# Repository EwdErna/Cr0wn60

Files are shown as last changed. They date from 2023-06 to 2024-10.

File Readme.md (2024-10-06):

# Cr0wn60

Cr0wn60 配下の特徴を持つキーボードです。

- TreadStone 配列ベースの左右対称配列
- RP2040 採用の PCB
- Friction O-ring Mount の 3 ピースケース

ファームウェアは以下のリポジトリから取得可能です。  
[Ewderna/qmk_firmware ewderna_22 branch](https://github.com/EwdErna/qmk_firmware/tree/dev/ewderna_22)

## Build Guide

### 同梱物

- PCB
  - デフォルトのファームウェアを書き込み済み
- スイッチプレート
- ケース
  - トップケース
  - ミドルプレート
  - ボトムケース
- O-ring ID185x3.55mm
- Unified Daughter Board S1 / molex Pico EasyMate Cable

> [!Note]  
> ProtoType 版ではスイッチプレート、ケースはデータのみの配布となります。  
> また、O-ring については付属しません。ご自身で購入をお願いします。

### 別途必要なもの

- キースイッチ x60
  - Cherry MX 互換のみ対応
- スタビライザー
  - PCBマウント 2U x3
- LED x15 (Optional)
  - SK6812MINI-E 互換品
- USB Type-C ケーブル
- キーキャップ x60
  - 1U x48
  - 1.25U x5
  - 1.5U x2
  - 1.75U x2
  - 2.25U x3

### 組み立て手順

#### LEDのはんだ付け(Optional)

15個のLEDをはんだ付けします。  

#### スタビライザーの取り付け

PCBにスタビライザーを取り付けます。  
PCB表面にスタビライザーのワイヤー側を示すシルクがあります。  
向きを間違えないよう注意してください。

#### スイッチプレートにキースイッチの取り付け

すべてのキースイッチをスイッチプレートに取り付けます。

#### キースイッチのはんだ付け

プレートごとキースイッチをPCBに取り付け、裏面からはんだ付けします。

#### 動作確認

UDBに付属のケーブルをUDB、PCBそれぞれのハウジングに取り付けます。  
PCとUDBをType-Cケーブルでつなぎ、[Remap](https://remap-keys.app)に接続します。  
CUSTOMIZE YOUR KEYBOARDからCr0wn60を選択したのち、Test Matrixモードを使用し全キーが反応することを確認します。  
オプションのLEDを取り付けている場合もここで確認します。  
> [!TIP]  
> LEDが途中から光らない場合は、光らないLEDかその直前の番号のLEDについてはんだ付けを見直してください。  
> はんだ付けを直しても光らない場合はLEDが壊れている可能性がありますので交換してみてください。

> [!TIP]  
> proto.1、proto.2ではLED番号が逆転しています。LED15が一番最初のLEDで、LED1が一番最後のLEDです。

#### O-ringの取り付け

スイッチプレートとPCBの隙間に、スイッチに引っかかるようにO-ringを取り付けます。  
下側左右の角部分に余裕を持たせるように掛けておくとケースに入れやすくなります。

#### ケースの組み立て

ボトムケース、ミドルプレート、トップケースの順に重ね、ボトムケースの裏側からM3ねじ8本で固定します。  
ミドルプレートの向きに気を付けてください。角の隙間が狭いほうが左側に来るように重ねます。

#### UDBの取り付け

UDBを、付属のねじでボトムケースに固定します。  
付属のケーブルをUDB、PCBのハウジングにそれぞれ取り付けます。向きは特にありません。

#### ケースにPCBの取り付け

PCBをケースに収めます。  
下側左右の角部分に張ったO-ringをトップケースの角に押し付けながら、上側をケース内に押し込みます。  
最後に奥まで押し込んで取付完了です。

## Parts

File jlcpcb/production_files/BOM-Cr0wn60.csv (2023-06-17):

Comment | Designator | Footprint | LCSC
1k | R3,R4,R5 | R_0402_1005Metric | C11702
0.1u | C1,C11,C2,C3,C4,C7,C8 | C_0402_1005Metric | C1525
10u | C10,C9 | C_0402_1005Metric | C15525
27p | C12,C13 | C_0402_1005Metric | C1557
RP2040_QFN_56 | U3 | QFN-56-1EP_7x7mm_P0.4mm_EP3.2x3.2mm | C2040
22 | R1,R2 | R_0402_1005Metric | C25092
SW_Push | SWR0,SWR1 | TS-1088R-02026 | C455280
YS-SK6812MINI-E-Small | LED1,LED10,LED11,LED12,LED13,LED14,LED15,LED2,LED3,LED4,LED5,LED6,LED7,LED8,LED9 | YS-SK6812MINI-E_rev | C5149201
1u | C5,C6 | C_0402_1005Metric | C52923
Conn_01x04_MountingPin | J1 | Pico-EZmate | C588524
AMS1117 | U1 | SOT-223-3_TabPin2 | C6186
D_Small | D1,DK1,DK10,DK12,DK13,DK14,DK15,DK16,DK17,DK2,DK20,DK21,DK23,DK24,DK25,DK26,DK3,DK30,DK31,DK32,DK34,DK35,DK36,DK37,DK4,DK40,DK41,DK42,DK43,DK45,DK46,DK5,DK50,DK51,DK52,DK53,DK54,DK56,DK57,DK6,DK60,DK61,DK62,DK63,DK64,DK65,DK70,DK71,DK72,DK73,DK74,DK75,DK76,DK80,DK81,DK82,DK83,DK84,DK85,DK86,DK87,DR0,DR1,DR2,DR3,DR4,DR5,DR6,DR7,DR8 | D_SOD-123 | C81598
12M | Y1 | Crystal_SMD_3225-4Pin_3.2x2.5mm | C9002
W25Q128JVS | U2 | SOIC-8_5.23x5.23mm_P1.27mm | C97521

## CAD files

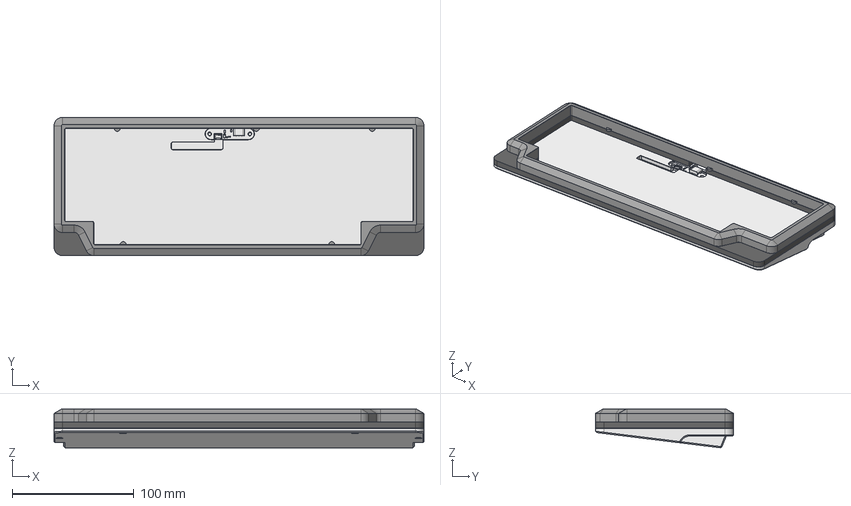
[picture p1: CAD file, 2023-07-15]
Case/proto1/Cr0wn60.FCStd
304.2 x 113.7 x 31.7 mm
uDB-S1-3D-model

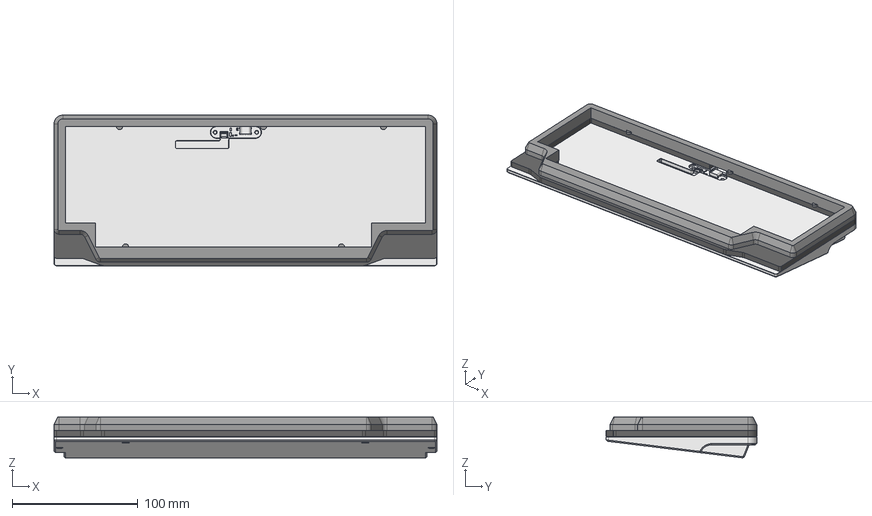
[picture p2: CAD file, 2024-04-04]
Case/proto2/Cr0wn60.FCStd
304.2 x 119.7 x 32.4 mm
uDB-S1-3D-model

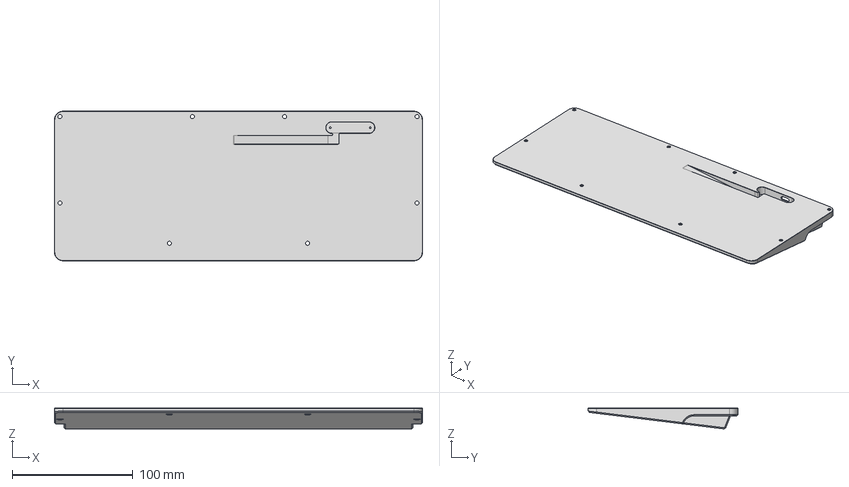
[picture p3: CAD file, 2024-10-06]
Case/proto3/Cr0wn60_2.FCStd
304.2 x 123.7 x 17.3 mm

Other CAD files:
Case/proto3/Cr0wn60_2.blend

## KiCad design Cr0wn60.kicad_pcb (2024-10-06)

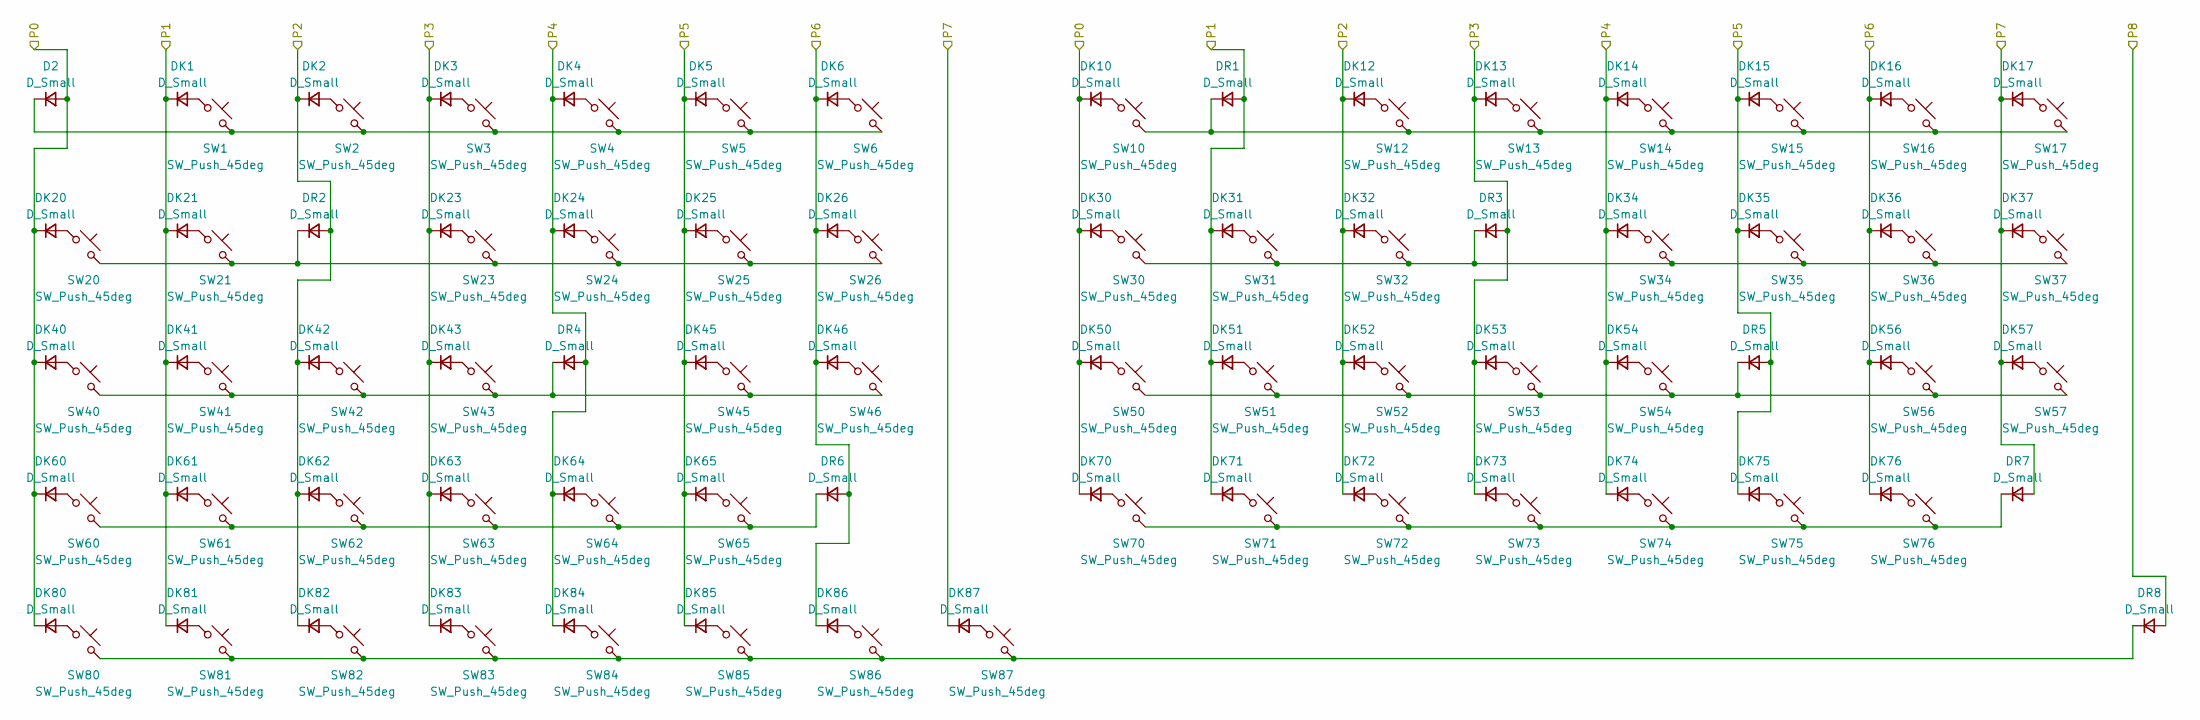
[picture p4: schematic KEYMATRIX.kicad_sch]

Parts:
D2: D_Small
DK1, DK2, DK3, DK4, DK5, DK6, DK10, DK12, DK13, DK14, DK15, DK16, DK17, DK20, DK21, DK23, DK24, DK25, DK26, DK30, DK31, DK32, DK34, DK35, DK36, DK37, DK40, DK41, DK42, DK43, DK45, DK46, DK50, DK51, DK52, DK53, DK54, DK56, DK57, DK60, DK61, DK62, DK63, DK64, DK65, DK70, DK71, DK72, DK73, DK74, DK75, DK76, DK80, DK81, DK82, DK83, DK84, DK85, DK86, DK87: D_Small; D_SOD-123
DR1, DR2, DR3, DR4, DR5, DR6, DR7, DR8: D_Small; D_SOD-123
SW1, SW2, SW3, SW4, SW5, SW6, SW10, SW12, SW13, SW14, SW15, SW16, SW17, SW21, SW23, SW24, SW25, SW26, SW30, SW31, SW32, SW34, SW35, SW36, SW41, SW42, SW43, SW45, SW46, SW50, SW51, SW52, SW53, SW54, SW56, SW61, SW62, SW63, SW64, SW65, SW70, SW71, SW72, SW73, SW74, SW75, SW82, SW85: SW_Push_45deg; SW_Cherry_MX1A_1.00u_PCB
SW20, SW37: SW_Push_45deg; SW_Cherry_MX1A_1.50u_PCB
SW40, SW76: SW_Push_45deg; SW_Cherry_MX1A_1.75u_PCB
SW57, SW83, SW84: SW_Push_45deg; SW_Cherry_MX1A_2.25u_PCB
SW60, SW80, SW81, SW86, SW87: SW_Push_45deg; SW_Cherry_MX1A_1.25u_PCB

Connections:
/P0: D2.2 (A), DK10.1 (K), DK20.1 (K), DK30.1 (K), DK40.1 (K), DK50.1 (K), DK60.1 (K), DK70.1 (K), DK80.1 (K); also elsewhere on the board
/P1: DK1.1 (K), DK21.1 (K), DK31.1 (K), DK41.1 (K), DK51.1 (K), DK61.1 (K), DK71.1 (K), DK81.1 (K), DR1.2 (A); also elsewhere on the board
/P2: DK2.1 (K), DK12.1 (K), DK32.1 (K), DK42.1 (K), DK52.1 (K), DK62.1 (K), DK72.1 (K), DK82.1 (K), DR2.2 (A); also elsewhere on the board
/P3: DK3.1 (K), DK13.1 (K), DK23.1 (K), DK43.1 (K), DK53.1 (K), DK63.1 (K), DK73.1 (K), DK83.1 (K), DR3.2 (A); also elsewhere on the board
/P4: DK4.1 (K), DK14.1 (K), DK24.1 (K), DK34.1 (K), DK54.1 (K), DK64.1 (K), DK74.1 (K), DK84.1 (K), DR4.2 (A); also elsewhere on the board
/P5: DK5.1 (K), DK15.1 (K), DK25.1 (K), DK35.1 (K), DK45.1 (K), DK65.1 (K), DK75.1 (K), DK85.1 (K), DR5.2 (A); also elsewhere on the board
/P6: DK6.1 (K), DK16.1 (K), DK26.1 (K), DK36.1 (K), DK46.1 (K), DK56.1 (K), DK76.1 (K), DK86.1 (K), DR6.2 (A); also elsewhere on the board
/P7: DK17.1 (K), DK37.1 (K), DK57.1 (K), DK87.1 (K), DR7.2 (A); also elsewhere on the board
/P8: DR8.2 (A); also elsewhere on the board
unnamed: DK1.2 (A), SW1.1
unnamed: DK2.2 (A), SW2.1
unnamed: DK3.2 (A), SW3.1
unnamed: DK4.2 (A), SW4.1
unnamed: DK5.2 (A), SW5.1
unnamed: DK6.2 (A), SW6.1
unnamed: DK10.2 (A), SW10.1
unnamed: DK12.2 (A), SW12.1
unnamed: DK13.2 (A), SW13.1
unnamed: DK14.2 (A), SW14.1
unnamed: DK15.2 (A), SW15.1
unnamed: DK16.2 (A), SW16.1
unnamed: DK17.2 (A), SW17.1
unnamed: DK20.2 (A), SW20.1
unnamed: DK21.2 (A), SW21.1
unnamed: DK23.2 (A), SW23.1
unnamed: DK24.2 (A), SW24.1
unnamed: DK25.2 (A), SW25.1
unnamed: DK26.2 (A), SW26.1
unnamed: DK30.2 (A), SW30.1
unnamed: DK31.2 (A), SW31.1
unnamed: DK32.2 (A), SW32.1
unnamed: DK34.2 (A), SW34.1
unnamed: DK35.2 (A), SW35.1
unnamed: DK36.2 (A), SW36.1
unnamed: DK37.2 (A), SW37.1
unnamed: DK40.2 (A), SW40.1
unnamed: DK41.2 (A), SW41.1
unnamed: DK42.2 (A), SW42.1
unnamed: DK43.2 (A), SW43.1
unnamed: DK45.2 (A), SW45.1
unnamed: DK46.2 (A), SW46.1
unnamed: DK50.2 (A), SW50.1
unnamed: DK51.2 (A), SW51.1
unnamed: DK52.2 (A), SW52.1
unnamed: DK53.2 (A), SW53.1
unnamed: DK54.2 (A), SW54.1
unnamed: DK56.2 (A), SW56.1
unnamed: DK57.2 (A), SW57.1
unnamed: DK60.2 (A), SW60.1
unnamed: DK61.2 (A), SW61.1
unnamed: DK62.2 (A), SW62.1
unnamed: DK63.2 (A), SW63.1
unnamed: DK64.2 (A), SW64.1
unnamed: DK65.2 (A), SW65.1
unnamed: DK70.2 (A), SW70.1
unnamed: DK71.2 (A), SW71.1
unnamed: DK72.2 (A), SW72.1
unnamed: DK73.2 (A), SW73.1
unnamed: DK74.2 (A), SW74.1
unnamed: DK75.2 (A), SW75.1
unnamed: DK76.2 (A), SW76.1
unnamed: DK80.2 (A), SW80.1
unnamed: DK81.2 (A), SW81.1
unnamed: DK82.2 (A), SW82.1
unnamed: DK83.2 (A), SW83.1
unnamed: DK84.2 (A), SW84.1
unnamed: DK85.2 (A), SW85.1
unnamed: DK86.2 (A), SW86.1
unnamed: DK87.2 (A), SW87.1
unnamed 92: D2.1 (K), SW1.2, SW2.2, SW3.2, SW4.2, SW5.2, SW6.2; also elsewhere on the board
unnamed: DR1.1 (K), SW10.2, SW12.2, SW13.2, SW14.2, SW15.2, SW16.2, SW17.2
unnamed: DR2.1 (K), SW20.2, SW21.2, SW23.2, SW24.2, SW25.2, SW26.2
unnamed: DR3.1 (K), SW30.2, SW31.2, SW32.2, SW34.2, SW35.2, SW36.2, SW37.2
unnamed: DR4.1 (K), SW40.2, SW41.2, SW42.2, SW43.2, SW45.2, SW46.2
unnamed: DR5.1 (K), SW50.2, SW51.2, SW52.2, SW53.2, SW54.2, SW56.2, SW57.2
unnamed: DR6.1 (K), SW60.2, SW61.2, SW62.2, SW63.2, SW64.2, SW65.2
unnamed: DR7.1 (K), SW70.2, SW71.2, SW72.2, SW73.2, SW74.2, SW75.2, SW76.2
unnamed: DR8.1 (K), SW80.2, SW81.2, SW82.2, SW83.2, SW84.2, SW85.2, SW86.2, SW87.2

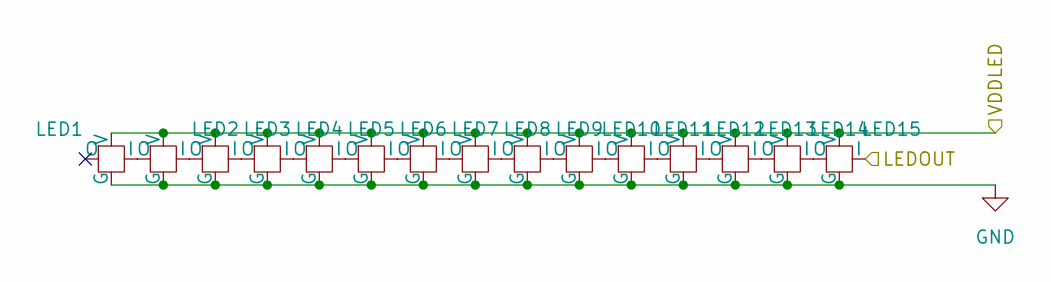
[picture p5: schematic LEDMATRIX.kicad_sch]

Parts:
LED1, LED2, LED3, LED4, LED5, LED6, LED7, LED8, LED9, LED10, LED11, LED12, LED13, LED14, LED15: YS-SK6812MINI-E-Small; YS-SK6812MINI-E_rev

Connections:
/LED: LED15.4 (I); also elsewhere on the board
/VDDLED: LED1.1 (V), LED2.1 (V), LED3.1 (V), LED4.1 (V), LED5.1 (V), LED6.1 (V), LED7.1 (V), LED8.1 (V), LED9.1 (V), LED10.1 (V), LED11.1 (V), LED12.1 (V), LED13.1 (V), LED14.1 (V), LED15.1 (V); also elsewhere on the board
GND: LED1.3 (G), LED2.3 (G), LED3.3 (G), LED4.3 (G), LED5.3 (G), LED6.3 (G), LED7.3 (G), LED8.3 (G), LED9.3 (G), LED10.3 (G), LED11.3 (G), LED12.3 (G), LED13.3 (G), LED14.3 (G), LED15.3 (G); also elsewhere on the board
unnamed: LED1.4 (I), LED2.2 (O)
unnamed: LED2.4 (I), LED3.2 (O)
unnamed: LED3.4 (I), LED4.2 (O)
unnamed: LED4.4 (I), LED5.2 (O)
unnamed: LED5.4 (I), LED6.2 (O)
unnamed: LED6.4 (I), LED7.2 (O)
unnamed: LED7.4 (I), LED8.2 (O)
unnamed: LED8.4 (I), LED9.2 (O)
unnamed: LED10.4 (I), LED11.2 (O)
unnamed: LED9.4 (I), LED10.2 (O)
unnamed: LED11.4 (I), LED12.2 (O)
unnamed: LED12.4 (I), LED13.2 (O)
unnamed: LED13.4 (I), LED14.2 (O)
unnamed: LED14.4 (I), LED15.2 (O)

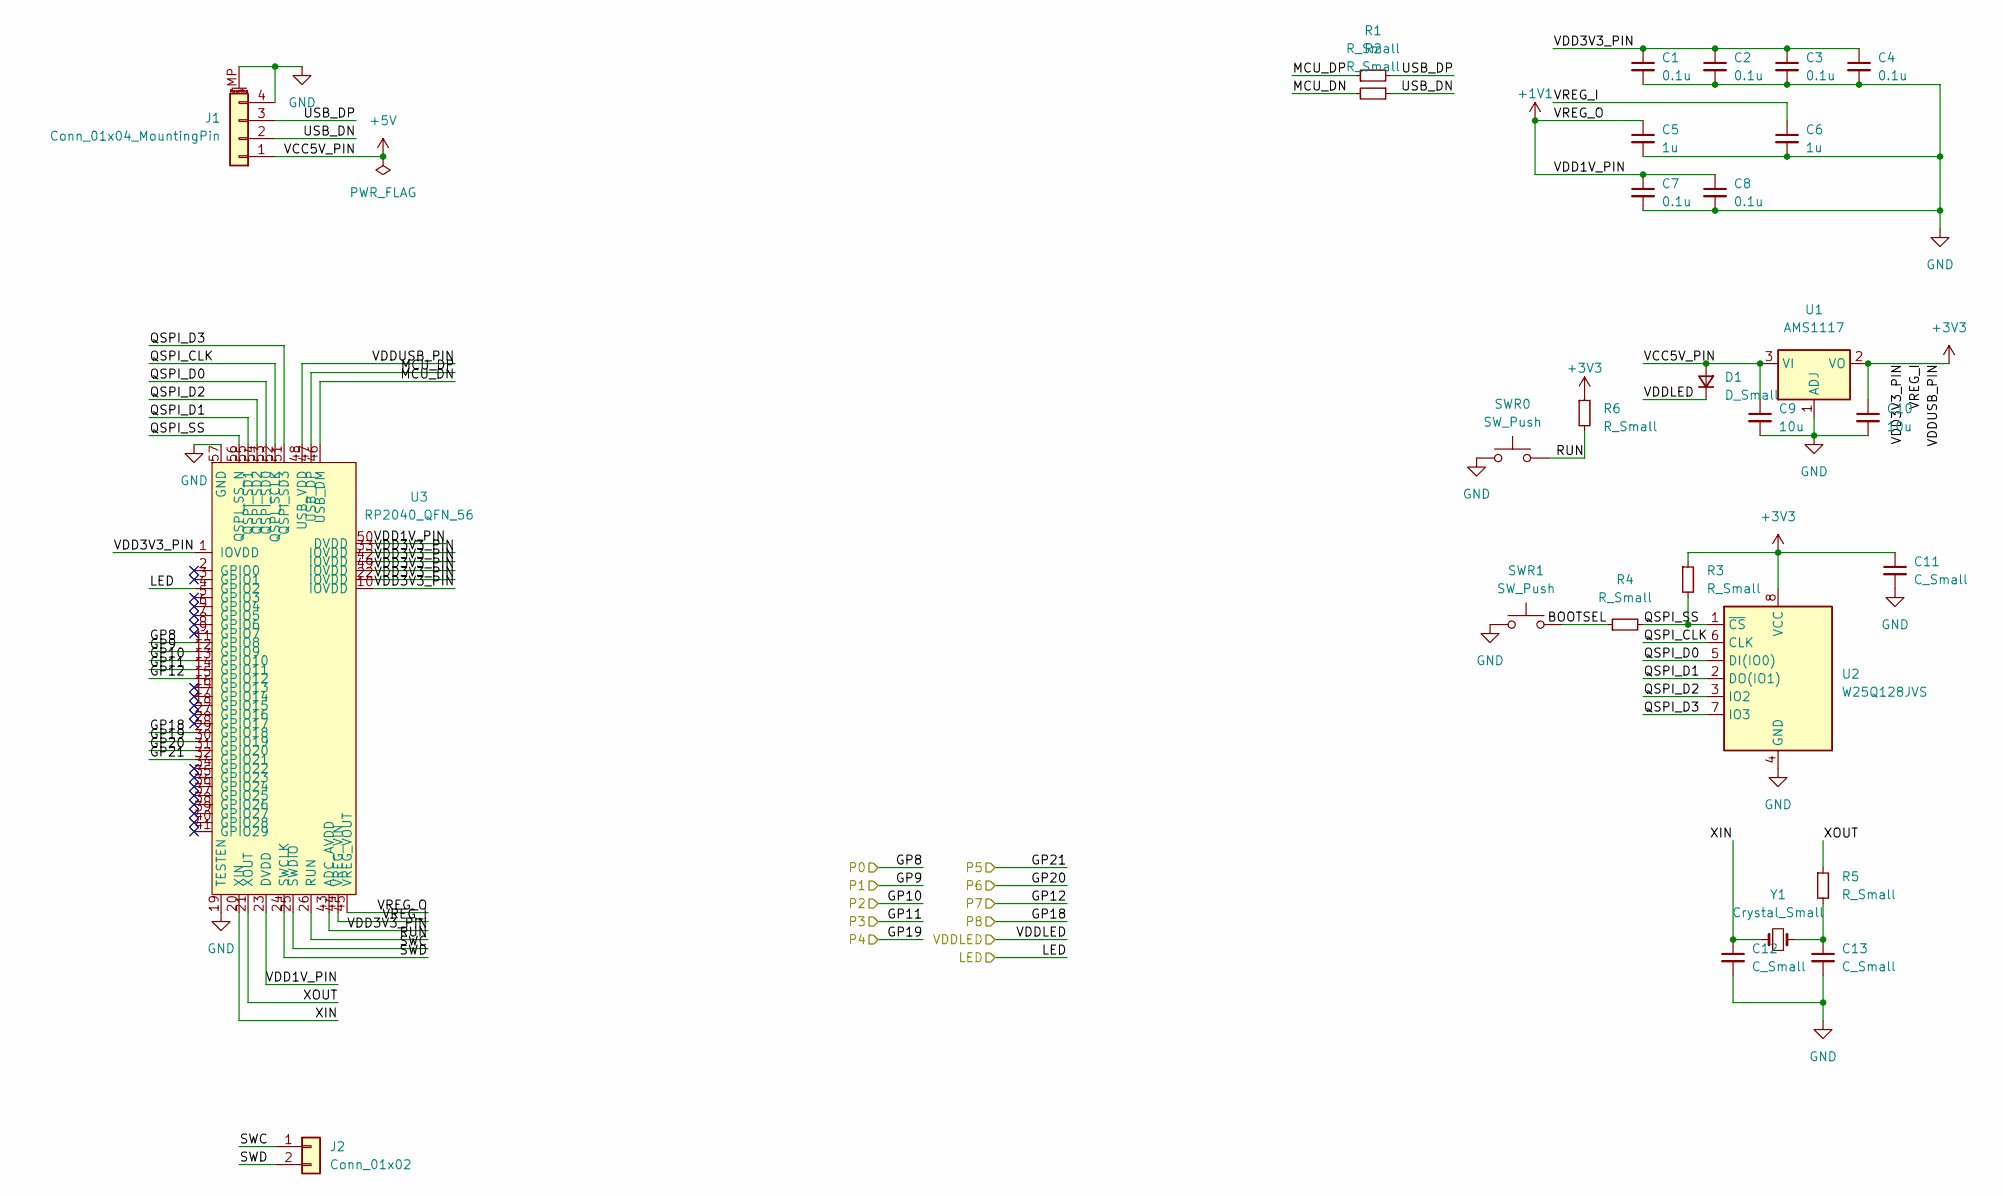
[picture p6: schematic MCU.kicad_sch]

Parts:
C1, C2, C3, C4, C7, C8: 0.1u; C_0402_1005Metric
C5, C6: 1u; C_0402_1005Metric
C9, C10: 10u; C_0402_1005Metric
C11, C12, C13: C_Small; C_0402_1005Metric
D1: D_Small; D_SOD-123
J1: Conn_01x04_MountingPin; Pico-EZmate
J2: Conn_01x02; PinSocket_1x02_P1.27mm_Vertical
R1, R2, R3, R4, R5: R_Small; R_0402_1005Metric
R6: R_Small
SWR0, SWR1: SW_Push; TVAF06-A020B-R
U1: AMS1117; SOT-223-3_TabPin2
U2: W25Q128JVS; SOIC-8_5.23x5.23mm_P1.27mm
U3: RP2040_QFN_56; QFN-56-1EP_7x7mm_P0.4mm_EP3.2x3.2mm
Y1: Crystal_Small; Crystal_SMD_3225-4Pin_3.2x2.5mm

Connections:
+1V1: C5.1, C7.1, C8.1, U3.23 (DVDD), U3.45 (VREG_VOUT), U3.50 (DVDD)
+3V3: C1.1, C2.1, C3.1, C4.1, C6.1, C10.1, C11.1, R3.1, R6.1, U1.2 (VO), U2.8 (VCC), U3.1 (IOVDD), U3.10 (IOVDD), U3.22 (IOVDD), U3.33 (IOVDD), U3.42 (IOVDD), U3.43 (ADC_AVDD), U3.44 (VREG_VIN), U3.48 (USB_VDD), U3.49 (IOVDD)
+5V: C9.1, D1.2 (A), J1.1, U1.3 (VI)
/LED: U3.4 (GPIO2); also elsewhere on the board
/MCU/BOOTSEL: R4.1, SWR1.2
/MCU/MCU_DN: R2.2, U3.46 (USB_DM)
/MCU/MCU_DP: R1.1, U3.47 (USB_DP)
/MCU/QSPI_CLK: U2.6 (CLK), U3.52 (QSPI_SCLK)
/MCU/QSPI_D0: U2.5 (DI(IO0)), U3.53 (QSPI_SD0)
/MCU/QSPI_D1: U2.2 (DO(IO1)), U3.55 (QSPI_SD1)
/MCU/QSPI_D2: U2.3 (IO2), U3.54 (QSPI_SD2)
/MCU/QSPI_D3: U2.7 (IO3), U3.51 (QSPI_SD3)
/MCU/QSPI_SS: R3.2, R4.2, U2.1 (~CS), U3.56 (QSPI_SS_N)
/MCU/RUN: R6.2, SWR0.2, U3.26 (RUN)
/MCU/SWC: J2.1, U3.25 (SWDIO)
/MCU/SWD: J2.2, U3.24 (SWCLK)
/MCU/USB_DN: J1.2, R2.1
/MCU/USB_DP: J1.3, R1.2
/MCU/XIN: C12.1, U3.20 (XIN), Y1.1
/MCU/XOUT: R5.1, U3.21 (XOUT)
/P0: U3.11 (GPIO8); also elsewhere on the board
/P1: U3.12 (GPIO9); also elsewhere on the board
/P2: U3.13 (GPIO10); also elsewhere on the board
/P3: U3.14 (GPIO11); also elsewhere on the board
/P4: U3.30 (GPIO19); also elsewhere on the board
/P5: U3.32 (GPIO21); also elsewhere on the board
/P6: U3.31 (GPIO20); also elsewhere on the board
/P7: U3.15 (GPIO12); also elsewhere on the board
/P8: U3.29 (GPIO18); also elsewhere on the board
/VDDLED: D1.1 (K); also elsewhere on the board
GND: C1.2, C2.2, C3.2, C4.2, C5.2, C6.2, C7.2, C8.2, C9.2, C10.2, C11.2, C12.2, C13.2, J1.4, J1.MP (MountPin), SWR0.1, SWR1.1, U1.1 (ADJ), U2.4 (GND), U3.19 (TESTEN), U3.57 (GND); also elsewhere on the board
unnamed: C13.1, R5.2, Y1.2

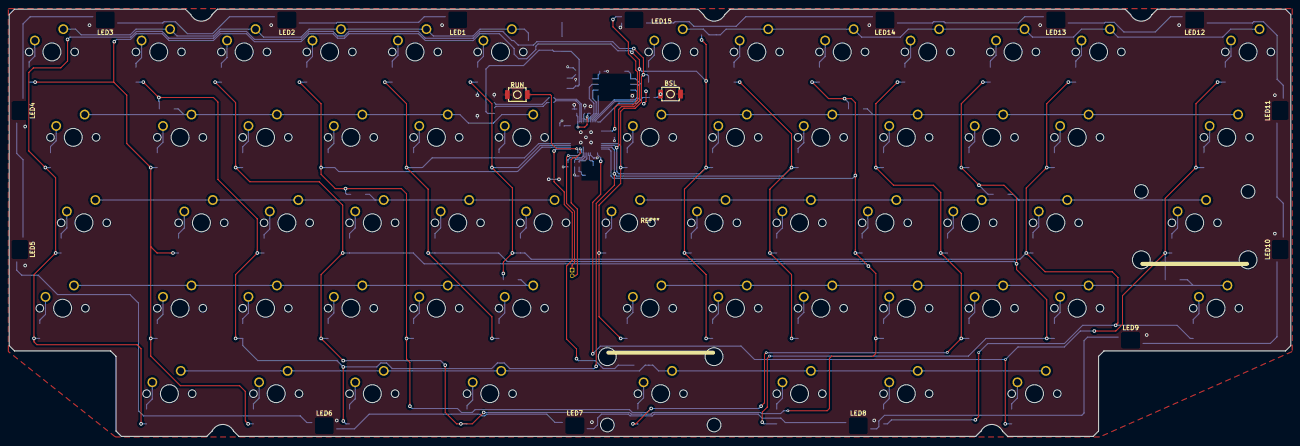
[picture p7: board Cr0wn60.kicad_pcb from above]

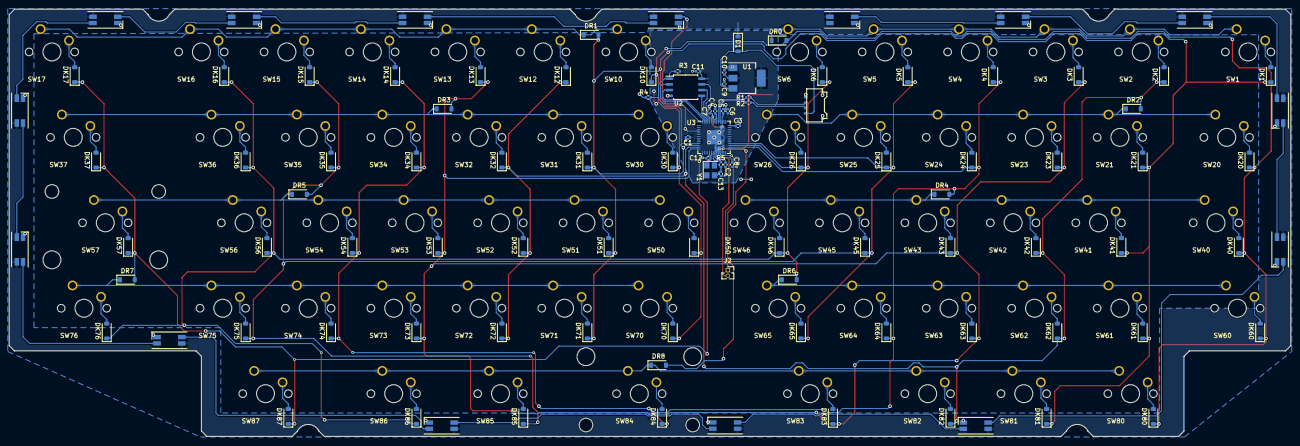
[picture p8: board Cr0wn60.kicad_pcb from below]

Board: 2 copper layers, 285.8 x 95.2 mm, 171 parts (109 on the bottom side), 115 nets.

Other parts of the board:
DR0: D_Small; D_SOD-123

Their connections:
/P0: DR0.2 (A); also elsewhere on the board
unnamed 92: DR0.1 (K); also elsewhere on the board

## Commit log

2023-06-17 add production files
    [BOM-Cr0wn60.csv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]
2023-07-02 add Case data
    [Cr0wn60.FCStd]
2023-07-09 wip: UDB-S1
    [Cr0wn60.FCStd]
2023-07-15 redesign (今度こそ)
    [Cr0wn60.FCStd]
2023-12-02 finished redesign
    [Cr0wn60.kicad_pcb, Cr0wn60_2.FCStd]
2024-04-04 ファイルを整理
    [Cr0wn60.FCStd, Cr0wn60_2.FCStd, Cr0wn60_2.blend]
2024-10-06 some tweak
    [Cr0wn60.kicad_pcb, Cr0wn60_2.FCStd, Cr0wn60_2.blend]
